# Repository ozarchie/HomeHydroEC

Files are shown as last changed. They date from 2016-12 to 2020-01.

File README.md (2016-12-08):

# HomeHydroEC
=============
An extension of Michael Ratcliffe's excellent EC project.   
<B>See the Project Wiki for a full description.  </B>  
https://github.com/ozarchie/HomeHydroEC/wiki  

## Extensions  
-------------
This project addresses the issue of polarization by implementing a square wave balanced resistor approach to measurement.  
An additional analog input channel is required.  
The 1k resistor is split in two as two 470R resistors and the probe inserted between the resistors.  
The voltage across the 470R sense resistor allows calculation of the sense current.  
The voltage across the prongs and the sense current allows determination of the electrical conductivity.  
An 18B20 sensor is connected to monitor the solution temperature.  

Schematic

Testing and documentation is underway. Documentation is included in the code.  

The Kcell of the probe is calculated using standard formula and measurements of the AC probe. 
EC Measurements agree well with Chinese TDC&EC meters.  
See the Project Wiki for a full description.  

## Original Work  

Original ideas and program published by -:  

www.MichaelRatcliffe.com/projects  
https://www.element14.com/community/community/design-challenges/vertical-farming/blog/2015/09/13/automated-green-house-blogs-main-page  
 
  28/8/2015  Michael Ratcliffe  Mike@MichaelRatcliffe.com

   This program is free software: you can redistribute it and/or modify
    it under the terms of the GNU General Public License as published by
    the Free Software Foundation, either version 3 of the License, or
    (at your option) any later version.

    This program is distributed in the hope that it will be useful,
    but WITHOUT ANY WARRANTY; without even the implied warranty of
    MERCHANTABILITY or FITNESS FOR A PARTICULAR PURPOSE.  See the
    GNU General Public License for more details.

    You should have received a copy of the GNU General Public License
    along with this program.  If not, see <http://www.gnu.org/licenses/>.

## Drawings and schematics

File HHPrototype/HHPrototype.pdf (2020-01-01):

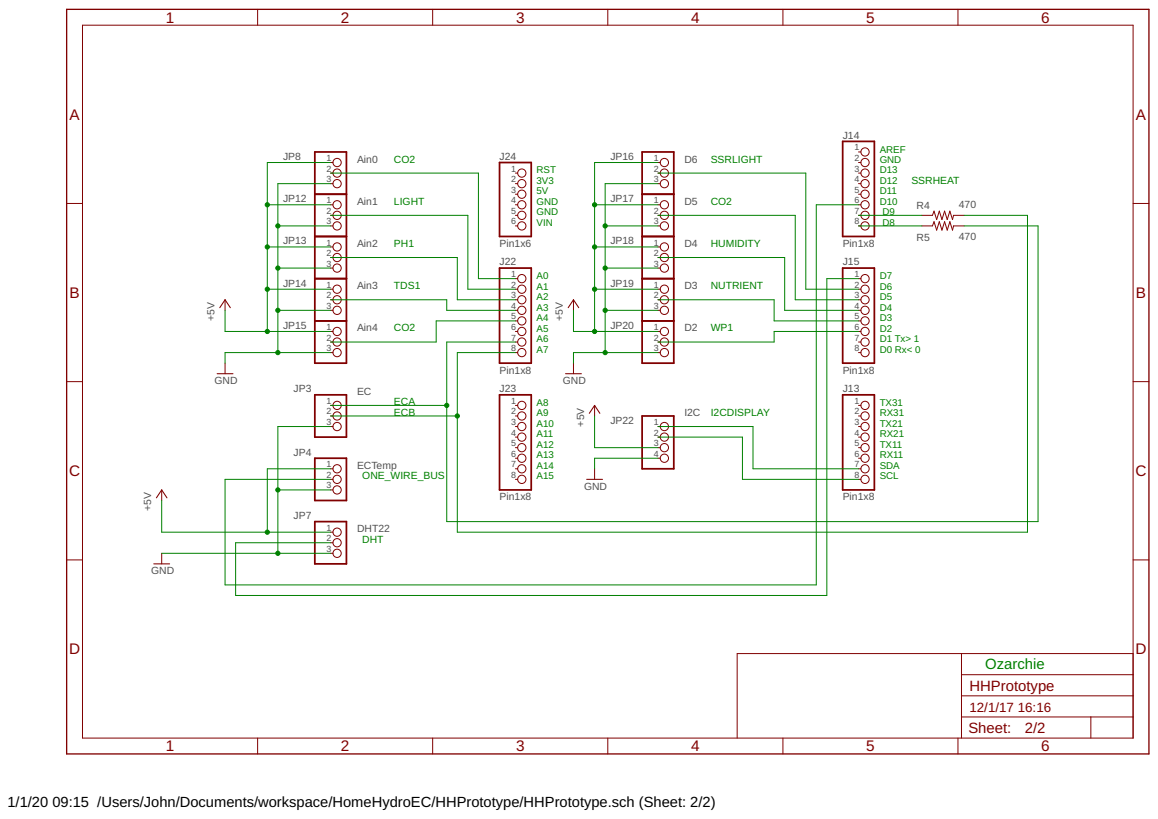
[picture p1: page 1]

1/1/20 09:15 /Users/John/Documents/workspace/HomeHydroEC/HHPrototype/HHPrototype.sch (Sheet: 2/2)

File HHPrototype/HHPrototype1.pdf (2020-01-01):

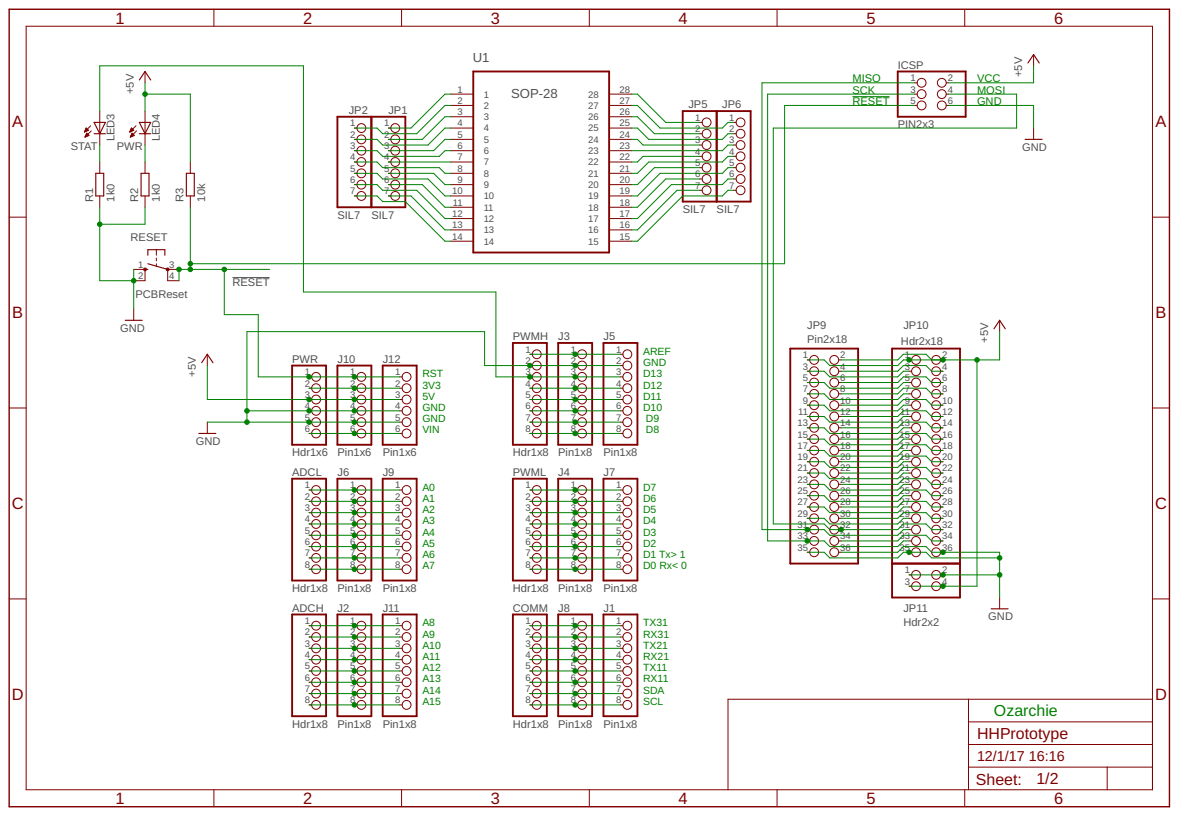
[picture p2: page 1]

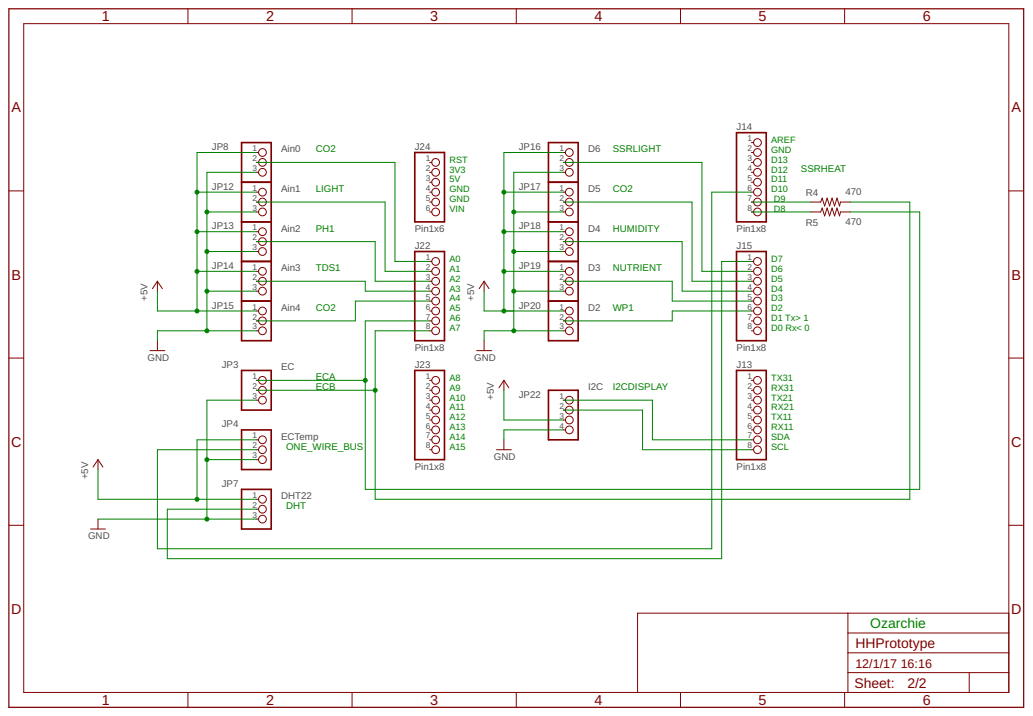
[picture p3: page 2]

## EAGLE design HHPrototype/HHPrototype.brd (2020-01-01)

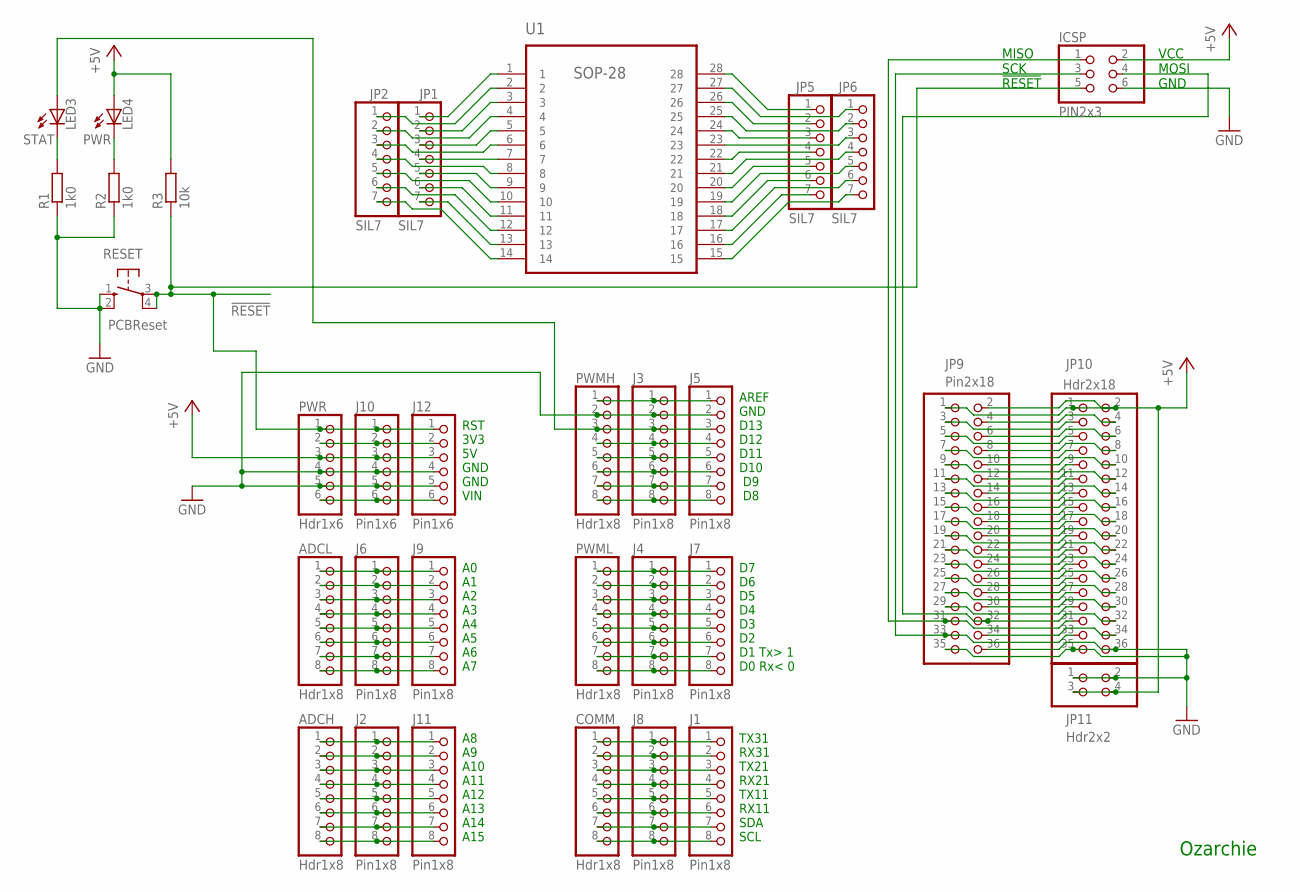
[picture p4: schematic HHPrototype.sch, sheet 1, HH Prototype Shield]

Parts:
ADCH: Hdr1x8; 1X08
ADCL: Hdr1x8; 1X08
COMM: Hdr1x8; 1X08
ICSP: PIN2x3; 2X03
J1, J2, J3, J4, J5, J6, J7, J8, J9, J11: Pin1x8; 1X08
J10, J12: Pin1x6; 1X06
JP1, JP2, JP5, JP6: SIL7; 1X07
JP9: Pin2x18; 2X18
JP10: Hdr2x18; 2X18
JP11: Hdr2x2; 2X02
LED3: STAT; CHIPLED_1206
LED4: PWR; CHIPLED_1206
PWMH: Hdr1x8; 1X08
PWML: Hdr1x8; 1X08
PWR: Hdr1x6; 1X06
R1, R2: 1k0; R0805
R3: 10k; R0805
RESET: PCBReset; B3F-10XX
U1: SOP-28; SOP50P1030X264-28N

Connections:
3V3: J10.2, J12.2, PWR.2
!RESET!: ICSP.5, J10.1, J12.1, PWR.1, R3.1, RESET.3, RESET.4 (P1)
+5V: ICSP.2, J10.3, J12.3, JP9.1, JP9.2, JP10.1, JP10.2, JP11.3, JP11.4, LED4.A, PWR.3, R3.2; also elsewhere on the board
A0: ADCL.1, J6.1, J9.1
A1: ADCL.2, J6.2, J9.2
A2: ADCL.3, J6.3, J9.3
A3: ADCL.4, J6.4, J9.4
A4: ADCL.5, J6.5, J9.5
A5: ADCL.6, J6.6, J9.6
A6: ADCL.7, J6.7, J9.7
A7: ADCL.8, J6.8, J9.8
A8: ADCH.1, J2.1, J11.1
A9: ADCH.2, J2.2, J11.2
A10: ADCH.3, J2.3, J11.3
A11: ADCH.4, J2.4, J11.4
A12: ADCH.5, J2.5, J11.5
A13: ADCH.6, J2.6, J11.6
A14: ADCH.7, J2.7, J11.7
A15: ADCH.8, J2.8, J11.8
AREF: J3.1, J5.1, PWMH.1
D0/RX0: J4.8, J7.8, PWML.8
D1/TX0: J4.7, J7.7, PWML.7
D2PWM: J4.6, J7.6, PWML.6
D3PWM: J4.5, J7.5, PWML.5
D4PWM: J4.4, J7.4, PWML.4
D5PWM: J4.3, J7.3, PWML.3
D6PWM: J4.2, J7.2, PWML.2
D7PWM: J4.1, J7.1, PWML.1
D8PWM: J3.8, J5.8, PWMH.8
D9PWM: J3.7, J5.7, PWMH.7
D10PWM: J3.6, J5.6, PWMH.6
D11PWM: J3.5, J5.5, PWMH.5
D12PWM: J3.4, J5.4, PWMH.4
D13PWM: J3.3, J5.3, LED3.A, PWMH.3
D14/TX3: COMM.1, J1.1, J8.1
D15/RX3: COMM.2, J1.2, J8.2
D16/TX2: COMM.3, J1.3, J8.3
D17/RX2: COMM.4, J1.4, J8.4
D18/TX1: COMM.5, J1.5, J8.5
D19/RX1: COMM.6, J1.6, J8.6
D20/SDA: COMM.7, J1.7, J8.7
D21/SCL: COMM.8, J1.8, J8.8
D22: JP9.3, JP10.3
D23: JP9.4, JP10.4
D24: JP9.5, JP10.5
D25: JP9.6, JP10.6
D26: JP9.7, JP10.7
D27: JP9.8, JP10.8
D28: JP9.9, JP10.9
D29: JP9.10, JP10.10
D30: JP9.11, JP10.11
D31: JP9.12, JP10.12
D32: JP9.13, JP10.13
D33: JP9.14, JP10.14
D34: JP9.15, JP10.15
D35: JP9.16, JP10.16
D36: JP9.17, JP10.17
D37: JP9.18, JP10.18
D38: JP9.19, JP10.19
D39: JP9.20, JP10.20
D40: JP9.21, JP10.21
D41: JP9.22, JP10.22
D42: JP9.23, JP10.23
D43: JP9.24, JP10.24
D44: JP9.25, JP10.25
D45: JP9.26, JP10.26
D46: JP9.27, JP10.27
D47: JP9.28, JP10.28
D48: JP9.29, JP10.29
D49: JP9.30, JP10.30
D53: JP9.34, JP10.34
GND: ICSP.6, J3.2, J5.2, J10.4, J10.5, J12.4, J12.5, JP9.35, JP9.36, JP10.35, JP10.36, JP11.1, JP11.2, PWMH.2, PWR.4, PWR.5, R1.1, R2.1, RESET.1 (S), RESET.2 (S1); also elsewhere on the board
MISO: ICSP.1, JP9.31, JP10.31
MOSI: ICSP.4, JP9.32, JP10.32
unnamed: LED3.C, R1.2
unnamed: LED4.C, R2.2
SCK: ICSP.3, JP9.33, JP10.33
SO1: JP1.1, U1.1
SO2: JP2.1, U1.2
SO3: JP1.2, U1.3
SO4: JP2.2, U1.4
SO5: JP1.3, U1.5
SO6: JP2.3, U1.6
SO7: JP1.4, U1.7
SO8: JP2.4, U1.8
SO9: JP1.5, U1.9
SO10: JP2.5, U1.10
SO11: JP1.6, U1.11
SO12: JP2.6, U1.12
SO13: JP1.7, U1.13
SO14: JP2.7, U1.14
SO15: JP6.7, U1.15
SO16: JP5.7, U1.16
SO17: JP6.6, U1.17
SO18: JP5.6, U1.18
SO19: JP6.5, U1.19
SO20: JP5.5, U1.20
SO21: JP6.4, U1.21
SO22: JP5.4, U1.22
SO23: JP6.3, U1.23
SO24: JP5.3, U1.24
SO25: JP6.2, U1.25
SO26: JP5.2, U1.26
SO27: JP6.1, U1.27
SO28: JP5.1, U1.28
VIN: J10.6, J12.6, PWR.6

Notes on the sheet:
RST 3V3 5V GND GND VIN
MISO SCK !RESET!
VCC MOSI GND
AREF GND D13 D12 D11 D10 D9 D8
D7 D6 D5 D4 D3 D2 D1 Tx> 1 D0 Rx< 0
A0 A1 A2 A3 A4 A5 A6 A7
A8 A9 A10 A11 A12 A13 A14 A15
TX31 RX31 TX21 RX21 TX11 RX11 SDA SCL
Ozarchie

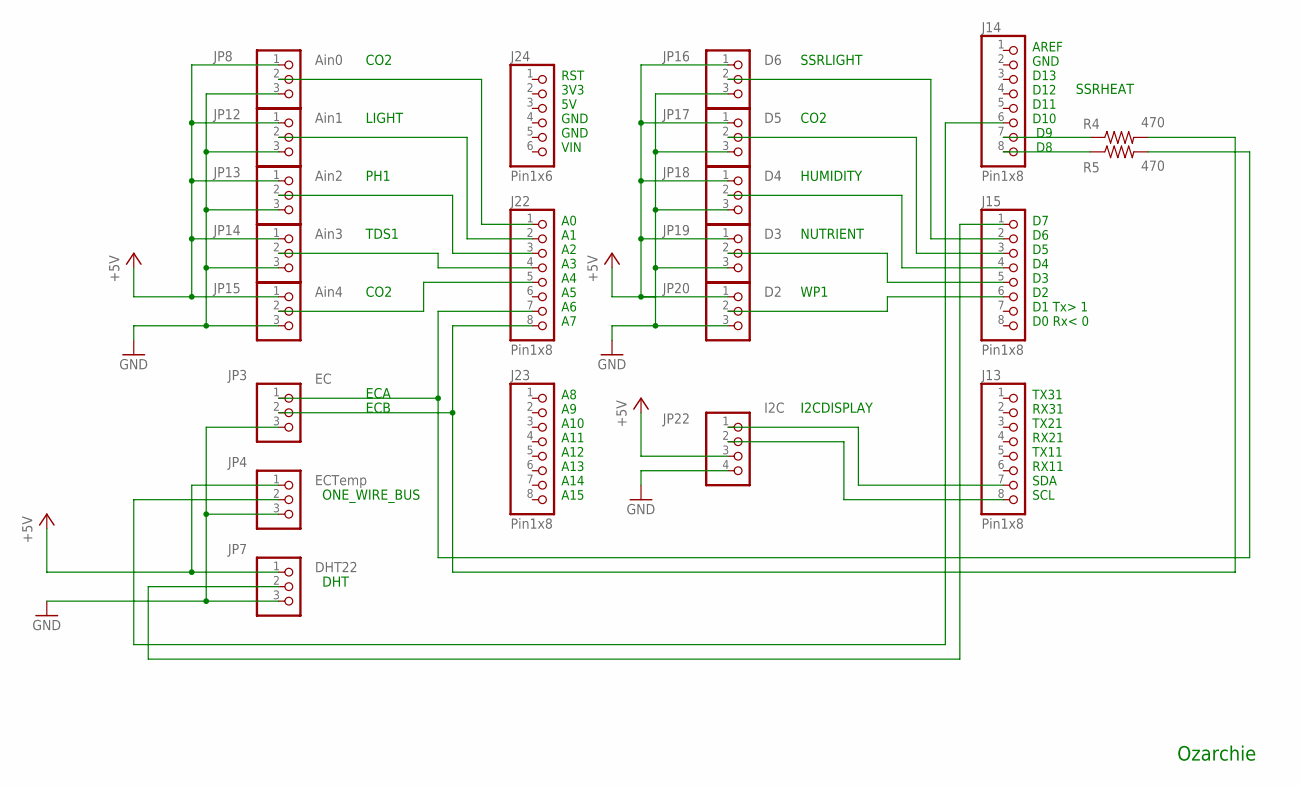
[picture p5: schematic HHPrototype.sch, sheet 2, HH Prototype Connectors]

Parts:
J13, J14, J15, J22, J23: Pin1x8; 1X08
J24: Pin1x6; 1X06
JP3: EC; 1X03
JP4: ECTemp; 1X03
JP7: DHT22; 1X03
JP8: Ain0; 1X03
JP12: Ain1; 1X03
JP13: Ain2; 1X03
JP14: Ain3; 1X03
JP15: Ain4; 1X03
JP16: D6; 1X03
JP17: D5; 1X03
JP18: D4; 1X03
JP19: D3; 1X03
JP20: D2; 1X03
JP22: I2C; 1X04
R4, R5: 470; 0207/2V

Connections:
+5V: JP4.1, JP7.1, JP8.1, JP12.1, JP13.1, JP14.1, JP15.1, JP16.1, JP17.1, JP18.1, JP19.1, JP20.1, JP22.3; also elsewhere on the board
GND: JP3.3, JP4.3, JP7.3, JP8.3, JP12.3, JP13.3, JP14.3, JP15.3, JP16.3, JP17.3, JP18.3, JP19.3, JP20.3, JP22.4; also elsewhere on the board
unnamed: J22.7, JP3.1, R5.2
unnamed: J15.6, JP20.2
unnamed: J15.5, JP19.2
unnamed: J15.4, JP18.2
unnamed: J15.3, JP17.2
unnamed: J15.2, JP16.2
unnamed: J22.1, JP8.2
unnamed: J22.2, JP12.2
unnamed: J22.3, JP13.2
unnamed: J22.4, JP14.2
unnamed: J22.5, JP15.2
unnamed: J13.7, JP22.1
unnamed: J13.8, JP22.2
unnamed: J15.1, JP7.2
unnamed: J22.8, JP3.2, R4.2
unnamed: J14.7, R4.1
unnamed: J14.6, JP4.2
unnamed: J14.8, R5.1

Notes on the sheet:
RST 3V3 5V GND GND VIN
A0 A1 A2 A3 A4 A5 A6 A7
A8 A9 A10 A11 A12 A13 A14 A15
Ozarchie
AREF GND D13 D12 D11 D10 D9 D8
D7 D6 D5 D4 D3 D2 D1 Tx> 1 D0 Rx< 0
TX31 RX31 TX21 RX21 TX11 RX11 SDA SCL
CO2
LIGHT
PH1
TDS1
ECA
ECB
SSRLIGHT
HUMIDITY
NUTRIENT
WP1
SSRHEAT
ONE_WIRE_BUS
DHT
I2CDISPLAY

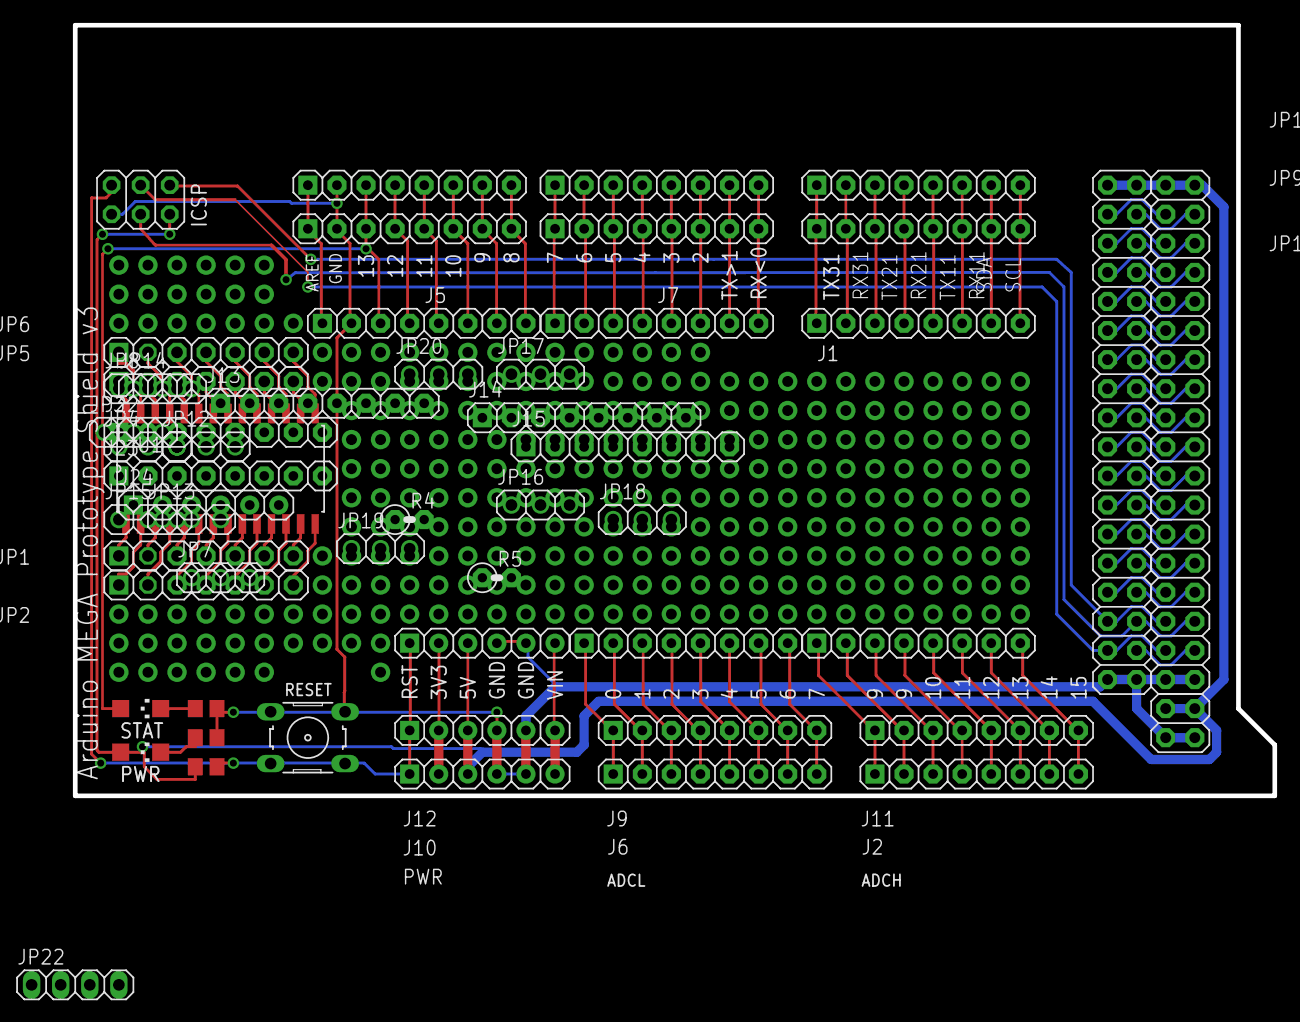
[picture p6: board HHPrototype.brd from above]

Board: 2 copper layers, 104.8 x 67.3 mm, 55 parts (0 on the bottom side), 124 nets.

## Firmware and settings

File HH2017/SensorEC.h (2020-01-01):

//*********** PPM Configuration Parameters ******************************//
// Hana      [USA]        PPMconversion:  0.5
// Eutech    [EU]         PPMconversion:  0.64
// Tranchen  [Australia]  PPMconversion:  0.7

#define PPMUS  0.5
#define PPMEU  0.64
#define PPMAu  0.7
#define PPM PPMAu               // <<<--- Change for your region

#define MAX_EC 10
#define MIN_EC 0
#define DEFAULT_EC 2

// Temperature defaults in centigrade
#define MAX_TEMP 60
#define MIN_TEMP -30
#define DEFAULT_TEMP 25

float PPMConst = PPM * 1000;    // Convert EC to ppm - Au

//************ EC Configuration Parameters *******************************//

float CalibrationKCl = 1.41;      // EC value of KCL Calibration solution (in mS/cm)
                                  // 0.01 D KCl solution @ 25°C
float CalibrationNaCl = 1014.9;   // EC value of NaCl Calibration solution (in uS/cm)
                                  // 0.05% NaCl solution @ 25°C
float TemperatureCoef = 0.019;    // Depends on chemical composition of solution
                                  // See below 0.019 = 1.9%/°C

float Rs = 470;                     // Current Sensing Resistor
float Ra = 25;                      // Estimated Source/Sink Resistance of powering Pins

float Vin = 5;                      // Power supply value

// Compensation for temperature
// ----------------------------
// conductivity = (Kcell / R) / (1 + (TemperatureCoef/100) * (T−25))


// Determination of the temperature coefficient (θ)
// ------------------------------------------------
//  By measuring the conductivity of a sample at temperature T1
//   close to Tref (25°C) and another temperature T2
//   coefficient by using the following equation:
//
//  θ = (κT2 - κT1) * 100 / (T2 - T1) * κT1
//   κT2 = Conductivity at T2
//   κT1 = Conductivity at T1
//  T2 should be approximately 10°C different from T1
//
// The temperature coefficients of the following electrolytes generally fall
// into the ranges shown below:
//  Acids: 1.0 - 1.6%/°C
//  Bases: 1.8 - 2.2%/°C
//  Salts: 2.2 - 3.0%/°C
//  Drinking water: 2.0%/°C
//  Ultrapure water: 5.2%/°C

//************ EC Probe Configuration Parameters **************************//

// Typical Conductivity values at 25°C
// -----------------------------------
//  Pure water            0.055 µS/cm
//  Deionised water       1 µS/cm
//  Rainwater             50 µS/cm
//  Drinking water        500 µS/cm
//  Industrial wastewater 5 mS/cm
//  Seawater              50 mS/cm
//  1 mol/l NaCl          85 mS/cm
//  1 mol/l HCl           332 mS/cm


// Calculate K from measurements of US style AC connector
// ------------------------------------------------------
// Area of prongs A = 2 * ((l * w) + (l * t)) // Side faces (two)
//                      + w * t               //  + End
//                      - 2 * (pi * r^2)      //  - Holes
//                      + (2 * pi * r) * t    //  + Internal annulus
//  where
//  l = length of prongs
//  w = width of prongs
//  t = thickness of prongs
//  r = radius of holes in prongs
//
// cell constant = Kcell = s/A
// ---------------------------
//  where
//  s = separation in cm between the electrodes (prongs)
//  A = area in cm2 of the electrodes (prongs)

// Input AC prong measurements in cm
// ---------------------------------
#define plength 1.7
#define pwidth 0.62
#define pthick 0.14
#define psepn 1.16
#define pradius 0.25
#define pi 3.17

// Calculated cell constant
// ------------------------
// One Prong Area = 2 * (Faces + sides) + end  - 2 * Circular hole + Internal annulus of hole
// float Ap = (2 * ((l * w) + (l * t))) + w * t - (2 * (pi * r * r)) + ((2 * pi * r) * t) ;
// float Kc = (s / (2 * Ap));          // Two prongs
// float K = Kc;                       // Calculated cell constant

// However, practice suggests that the other face and sides on each prong only contribute to 'fringe' effects.
// so ...
float  Ap = (plength * pwidth) + (plength * pthick) - pi * pradius * pradius;     // Surface area of one prong
float  Kc = (psepn / (2 * Ap));                                                   // Two prongs
float  K = Kc;

//************ EC Probe Related ******************************************//
int Polarity = 0;               // Polarity for this reading

float EC = 0;                     // EC - Temerature Compensated
float ECu = 0 ;                   // Uncompensated
int ppm = 0;                      // parts per million
char Units = 'm';                 // mS or uS

#define typeEC 0                // EC - Temerature Compensated
#define typeECu 1               // EC - UnCompensated
#define typePPM 2               // ppm - Temerature Compensated
#define typeRc 3                // Raw solution resistance - uncompensated

float ECVolts;                  // Sensing variables
float RsVolts;
float Vdrop = 0;
float Rc = 0;
float Ic = 0;

// The conductivity of a solution
// ------------------------------
// EC = K * G
// EC = K / R
// EC = conductivity (S/cm)
// G  = conductance (S), where G = 1/R
// K  = cell constant (cm-1)

// Frequency of measurements
// -------------------------
//  Measuring frequencies of a typical conductivity meter
//  94 Hz     in 4.000 µS and 40.00 µS ranges
//  46.9 Hz  in 400.0 mS and 2.000 S ranges
#define ECDelay 50              // 25 Hz

// Analog reference options
// ------------------------
// DEFAULT: the default analog reference of 5 volts (on 5V Arduino boards) or 3.3 volts (on 3.3V Arduino boards)
// INTERNAL: an built-in reference, equal to 1.1 volts on the ATmega168 or ATmega328 and 2.56 volts on the ATmega8 (not available on the Arduino Mega)
// INTERNAL1V1: a built-in 1.1V reference (Arduino Mega only)
// INTERNAL2V56: a built-in 2.56V reference (Arduino Mega only)
// EXTERNAL: the voltage applied to the AREF pin (0 to 5V only) is used as the reference.

#define AVolts Vin/1024           // = 5.00/1024

float ECTemperatureStart = 23.0;
float ECTemperatureFinish = 23.0;
 
float temp;

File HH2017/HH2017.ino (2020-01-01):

#include <avr/pgmspace.h>
#include "Arduino.h"

#include <Time.h>
#include <DS1307RTC.h>
#include <RTClib.h>

#include <Wire.h>
#include <LiquidCrystal_I2C.h>

#include <OneWire.h>
#include <DallasTemperature.h>

#include <DHT.h>   // Latest DHTnn library

#include "SensorEC.h"

#include <EEPROM.h>
#include "E2P_Map.h"

/*
//VARIABLES
*/
#define MSG_INTERVAL 10
#define LCD_INTERVAL 100

boolean stringComplete = false;
int serialcounter = 0;
int serialincounter = 0;

char SerialBuffer[80] = { 1,1,1,1,1,1,1,1,1,1,              // Testing, until the problem with PString() was found
                          2,2,2,2,2,2,2,2,2,2,
                          3,3,3,3,3,3,3,3,3,3,
                          4,4,4,4,4,4,4,4,4,4,
                          5,5,5,5,5,5,5,5,5,5,
                          6,6,6,6,6,6,6,6,6,6,
                          7,7,7,7,7,7,7,7,7,7,
                          8,8,8,8,8,8,8,8,8,8
                          };
int  pSerialBuffer = 0;
char* message[16] = {0,0,0,0,0,0,0,0,0,0,0,0,0,0,0,0};      // Maximum 16 elements in array

// RTC Interface
// -------------
tmElements_t tm;

char longdate[25] = "Jan  1, 2017 12:00:00 AM";
// char pH1_char[7] = "00.00";
// char pH2_char[7] = "00.00";
char Temp_char[8]= "";
char RH_char[7] = "00.00%";
char TDS1_char[11] = "0000.0ppm";
char TDS2_char[11] = "0000.0ppm";
char CO2_char[8] = "00.00%";
char Light_char[8] = "00.00%";

//Committed Light Settings
int Light_ON_hour = 18;
int Light_ON_min = 0;
int Light_OFF_hour = 6;
int Light_OFF_min = 0;

// Committed Pump Schedule Settings
// -------------------------------
int Pump_start_hour = 7;
int Pump_start_minute = 15;
int Pump_start_isAM = true;
int Pump_every_hours = 1;
int Pump_every_mins = 0;
int Pump_for = 15; //In Minutes
int Pump_repeat = 12; //Number of times per day

// Allow for pump schedules (Set in E2P_Map.h)
int Pump_hour_array[MAXREPEAT];
int Pump_minute_array[MAXREPEAT];
int Pump_isAM_array[MAXREPEAT];

/*
  SENSOR VARIABLES
 */
//Values the arduino sees
int pH1RawValue = 0;
int pH2RawValue = 0;
int TempRawValue = 0;
int RHRawValue = 0;
int TDS1RawValue = 0;
int TDS2RawValue = 0;
int CO2RawValue = 0;
int LightRawValue = 0;

//Values the humans see (after it has been calculated using raw values above ^^^ and their respected formulas)
float pH1Value = 0;
float pH2Value = 0;
float TempValue = 0;
float RHValue = 0;
float TDS1Value = 0;
float TDS2Value = 0;
float CO2Value = 0;
float LightValue = 0;

//PH
//Status Indicator Values
char  pH1_Status[4] = "OK";
float pH1Value_Low = 5.60;
float pH1Value_High = 6.10;
char  pH2_Status[4] = "OK";
float pH2Value_Low = 5.60;
float pH2Value_High = 6.10;

//Temp
char  Temp_Status[4] = "OK";
float TempValue_Low = 5.00;
float TempValue_High = 21.00;
//Accessory ON/OFF Values
float Heater_ON = 5.00;
float Heater_OFF = 21.00;
float AC_ON = 29.00;
float AC_OFF = 21.00;

//Humidty(RH)
char  RH_Status[4] = "OK";
float RHValue_Low = 30.00;
float RHValue_High = 80.00;
//Accessory ON/OFF Values
float Humidifier_ON = 40.00;
float Humidifier_OFF = 60.00;
float Dehumidifier_ON = 80.00;
float Dehumidifier_OFF = 60.00;

//TDS1
char  TDS1_Status[4] = "OK";
float TDS1Value_Low = 500.0;
float TDS1Value_High = 800.0;
//Accessory ON/OFF Values
float NutePump1_ON = 500.0;
float NutePump1_OFF = 800.0;
boolean MixPump1_Enabled = true;

//TDS2
char  TDS2_Status[4] = "OK";
float TDS2Value_Low = 500.0;
float TDS2Value_High = 800.0;
//Accessory ON/OFF Values
float NutePump2_ON = 500.0;
float NutePump2_OFF = 800.0;
boolean MixPump2_Enabled = true;

//CO2
char  CO2_Status[4] = "OK";
float CO2Value_Low = 60.00;
float CO2Value_High= 75.00;
//Accessory ON/OFF Values
float CO2_ON = 40.00;
float CO2_OFF = 60.00 ;
boolean CO2_Enabled = true;

//Light
char  Light_Status[4] = "OK";
float LightValue_Low = 20.00;
float LightValue_High = 95.00;


/*
 PIN DEFINITIONS
 */

 // Use analog reference
 
//float ArefValue = 5000.0 / 1024.0;   // Using default reference
float ArefValue = 2560.0 / 1024.0;   // Using 2V56 reference
//float ArefValue = 1100.0 / 1024.0;   // Using 1V1  reference

 // Analog pins
 // ===========
int CO2Pin = A0;
int LightPin = A1;
int pH1Pin = A2;
int pH2Pin = A2;
int TDS1Pin = A3;
int TDS2Pin = A3;
#define MAXINPUTS 8
int Input_Pin[MAXINPUTS] = { A0, A1, A2, A3, A4, A5, A6, A7 };

int pH1Ref = A5;        // Reference voltage from probe
int pH1Pwr = 12;        // Power for probe
#define NSAMPLES 10

// RH - DHT22 device for temperature and humidity
//#define DHTTYPE DHT11   // DHT 11
#define DHTTYPE DHT22   // DHT 22  (AM2302), AM2321
//#define DHTTYPE DHT21   // DHT 21 (AM2301)
#define DHTPIN 7                // DHT-22 on D7
DHT dht(DHTPIN, DHTTYPE);

// EC Probe Related
int ECAin=A6;                   // Probe A Sense Pin
int ECBin=A7;                   // Probe B Sense Pin 
int ECA=8;                      // Probe A Drive Pin
int ECB=9;                      // Probe B Drive Pin

// EC Temp Probe Related
#define EC_1WIRE 10             // Data wire For EC Temp Probe is plugged into pin D10 on the Arduino
OneWire ecWire(EC_1WIRE);      // Setup a oneWire instance to communicate with any OneWire devices
DallasTemperature ec_temp(&ecWire);  // Pass our oneWire reference to Dallas Temperature

// Water Temp Probe Related
#define WT_1WIRE 11         // Data wire For Water Temp Probes is plugged into pin D11 on the Arduino
OneWire wtWire(WT_1WIRE);  // Setup a oneWire instance to communicate with any OneWire devices
DallasTemperature wt_temp(&wtWire);// Pass our oneWire reference to Dallas Temperature

// Realtime Clock I2C - SDA/SCL
DS1307RTC rtc;

// LCD Display Related 
// Set the pins on the I2C chip used for LCD connections:
//                    addr, en,rw,rs,d4,d5,d6,d7,bl,blpol
LiquidCrystal_I2C lcd(0x27, 2, 1, 0, 4, 5, 6, 7, 3, POSITIVE);  // Set the LCD I2C address

// Digital pins
// ============
// Relays, SSR
// -----------
// Currently 6 relays
// MAXRELAYS set in E2P_Map.h
// Relays 5, 6 are SSR polarity

// Relay1_Pin = 2;  // Water Pump
// Relay2_Pin = 3;  // Nutrient
// Relay3_Pin = 4;  // Humidity
// Relay4_Pin = 5;  // CO2
// Relay5_Pin = 6;  //SSR (Light/Ballast)
// Relay6_Pin = 13; //SSR (Heater)

#define ON 1
#define OFF 0

#define WATERPUMP1 0
// #define WP2 1
#define NUTRIENT 1
#define HUMIDITY 2
#define pHADJUST 3
#define SSRLIGHT 4
#define SSRHEAT 5

int Relay_Pin[MAXRELAYS] = { 2, 3, 4, 5, 6, 13, 11, A15 };
uint8_t Relay_State[MAXRELAYS];
uint8_t Relay_isAuto[MAXRELAYS];

// Utility functions
// =================
boolean UIToStr(char *str, unsigned int val, uint8_t len, uint8_t dp)
{
  if (len > 5) return false;
  if (dp > len) return false;
  str += len;          // Point to end of string
  if (dp) str += 1;    //  add '.' if required
  *str = '\0';         // NULL terminate

  while (len--)
  {
    *--str = (val % 10) + '0';
    val /= 10;
    if ((--dp) == 0) *--str = '.'; 
  }
  return true;
}
boolean uint8ToStr(char *str, uint8_t val, uint8_t len, uint8_t dp)
{
  if (len > 3) return false;
  if (dp > len) return false;
  str += len;          // Point to end of string
  if (dp) str += 1;    //  add '.' if required
  *str = '\0';         // NULL terminate

  while (len--)
  {
    *--str = (val % 10) + '0';
    val /= 10;
    if ((--dp) == 0) *--str = '.'; 
  }
  return true;
}
/*
 SETUP
 */
void setup()
{
  int i;
  // Setup serial for boot reporting
  Serial.begin(9600);
  // SetuLCD for display
  //lcd.setBacklightPin ( BACKLIGHT_PIN, POSITIVE );
  //lcd.setBacklight ( HIGH );
  lcd.backlight();
  lcd.begin(20,4);               // initialize the lcd 
  lcd.home ();                   // go home
  
  lcd.setCursor ( 0, 2 );        // go to the third line
  lcd.print("HH Vers V17.0709"); 
  Serial.println("HH Vers V17.0709");
//  delay(50);    // Let user read, and wait for EEPROM  

  //Set Pin Modes for Inputs
  for (i = 0; i < MAXINPUTS; i++) {
    pinMode(Input_Pin[i], INPUT);
  }
  analogReference(INTERNAL2V56);

  // Setup EC Probe fir Input/Output
  EC_setup();
  
  //Set Pin Modes for Relays
  for (i = 0; i < MAXRELAYS; i++) {
    pinMode(Relay_Pin[i], OUTPUT);
  }
  pinMode(pH1Pwr, OUTPUT);
  
  // Read RTC
  // --------
  RestoreRTC();
  updatelongdate();
//  printtime();

//  Serial.println("Reading EEPROM into memory");
  // Load (and crc check) the E2P region values
  // If the region crc is wrong, load defaults

//  dumpcrc();
//  printE2PValues();
  lcd.setCursor ( 0, 3 );        // go to the bottom line  
  i = loadE2PValues();
  if (i != 0) {
    Serial.print("crc error count - ");
    Serial.println(i, DEC);
    lcd.print("EEPROM crc error");
    Serial.println(" Errors in EEPROM stored Values - enable print for details");
    dumpcrc();
    Serial.println("Defaults restored for values with errors");
    saveE2PValues();
    Serial.println("New values saved");
    dumpcrc();
    }
    else {
      lcd.print("EEPROM values loaded");
    }
    delay(1000);
}


/*
 LOOP
 */
 
void loop()
{
  char Month_array[12][4] = {"Jan","Feb","Mar","Apr","May","Jun","Jul","Aug","Sep","Oct","Nov","Dec"};
  int msgcount = 1;  // For sensor/relay messages
  int lcdcount = 1;  // For LCD Update
  
//  sendAllMessages();
  while (1) {
    if (msgcount > MSG_INTERVAL) {
//      updateSensorValues();
      sendserialmessages();
      CheckTimers();
      CheckSetPoints();
      msgcount = 0;
    }
    // Show on display
    if (lcdcount == 1) {
//      lcd.clear();
      lcd.setCursor ( 0, 0 );        // go to the top line
      if (hour() < 10) lcd.print(" ");
      lcd.print (hour());
      lcd.print(":");
      if (minute() < 10) lcd.print("0");
      lcd.print (minute());
      lcd.print(".");
      if (second() < 10) lcd.print("0");
      lcd.print (second());

//      lcd.setCursor ( 0, 1 );        // go to the bottom line
//      lcd.print("/");
//      lcd.print (year() % 2000);
//      if (month() < 10) lcd.print(" ");
      lcd.print("  ");
      lcd.print (Month_array[month()-1]);
      lcd.print(" ");
//      if (day() < 10) lcd.print(" ");
      lcd.print (day());
      
      lcd.setCursor ( 0, 1 );        // go to the bottom line
      lcd.print("pH ");
      lcd.print (pH1Value);
      lcd.setCursor ( 8, 1 );
      lcd.print("Lux ");
      lcd.print(LightValue);

    }
    if (lcdcount == LCD_INTERVAL) {
//      lcd.clear();
      lcd.setCursor ( 0, 0 );        // go to the top line
      lcd.print("RH ");
      lcd.print(RHValue);
      lcd.setCursor ( 8, 0 );
      lcd.print(" T ");
      lcd.print (TempValue);
      lcd.setCursor ( 0, 1 );        // go to the bottom line
      lcd.print("pp ");
      lcd.print (TDS1Value);
      lcd.setCursor ( 8, 1 );
      lcd.print(" T ");
      lcd.print(ECTemperatureFinish);
    }
    serialEvent();
    msgcount += 1;
    lcdcount += 1;
    if (lcdcount > LCD_INTERVAL*2) lcdcount = 0;
    delay(50);
  }
}

void printtime(void) {
  Serial.print(longdate);
  Serial.println();
}

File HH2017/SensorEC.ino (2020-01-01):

/*
  Electrical Conductivity Probes
  */


void EC_setup()
{

  pinMode(ECAin,INPUT);         // Always inputs
  pinMode(ECBin,INPUT);
}

/*
void EC_calibrate()
{
//  readTemp(0);                  // Read temperature
//  calibrateK();               // Calibrate K
  tod = now();
  EC=readECProbe(typeEC);

  if (EC < 1) {                 // Set display units
    EC *= 1000;
    ECu *= 1000;
    Units = 'u';
  }
  else if (EC < 1000) {
    EC *= 1000;
    ECu *= 1000;
    Units = 'm';    
  }
  else if (EC > 1000) {
    EC /= 1000;
    ECu /= 1000;
    Units = ' ';    
  }
  
  lcd.clear();
  lcd.setCursor ( 0, 0 );        // go to the top line
  lcd.print ("EC");
  lcd.setCursor ( 10, 0 );
  lcd.print(EC);
  lcd.print(Units);
  lcd.print("S");
  lcd.setCursor ( 0, 1 );        // go to the next line
  lcd.print ("EC (cal)");
  lcd.setCursor ( 10, 1 );
  lcd.print(CalibrationNaCl);
  lcd.print("uS");
  lcd.setCursor ( 0, 2 );        // go to the next line 
  lcd.print("Kcell");
  lcd.setCursor ( 10, 2 );
  lcd.print(K);
  lcd.setCursor ( 0, 3 );        // go to the next line    
  lcd.print("Ts ");
  lcd.print(TemperatureStart);
  lcd.setCursor ( 10, 3 ); 
  lcd.print("Tf ");
  lcd.print(TemperatureFinish);
    
  if ((TemperatureStart-TemperatureFinish) <= .2){
    Serial.print("Temperature stable to .2C - ");
    Serial.print("Ts ");
    Serial.print(j);
    Serial.print(", ");
    Serial.print(tod);
    Serial.print(", ");
    Serial.print(K);
    Serial.print(", ");
    Serial.print(TemperatureFinish);
    Serial.print(", ");
    Serial.print(ECu);
    Serial.print(", ");
    Serial.print(EC);
    Serial.print(", ");
    Serial.print(Rc);
    Serial.print(", ");             // Debug print
    Serial.println(Ic * 1000);

           
//    Serial.print("Calibration Solution EC: ");
//    Serial.print(CalibrationNaCl);
//    Serial.print("mS");

  }
  else{
    Serial.println("  Error - Wait For Temperature To settle");
    Serial.print("Ts ");
    Serial.print(TemperatureStart);
    Serial.print(", Tf ");
    Serial.print(TemperatureFinish);
  }
  delay(10000);
  j += 1;
}
*/

float readTemp(int tsensor) {
  float x;
  ec_temp.requestTemperatures(); // Send the command to get temperatures
  temp=ec_temp.getTempCByIndex(tsensor);
  if ((temp > MAX_TEMP) || (temp < MIN_TEMP)) temp = DEFAULT_TEMP;
  return(temp);
}


// Read data from EC probe
// -----------------------
// type typeEC  0   T Compensated Electrical conductivity
// type typeECu 1   Uncompensated Electrical conductivity
// type typePPM 2   T Compensated ppm
// type typeRc  3   Uncompensated Electrical Resistance

float EC_read(int type) {

  int i = 0;
  float x;
  ECVolts = 0;
  RsVolts = 0;
  Polarity = 0;
  
  ECTemperatureStart = readTemp(0);  // Read temperature   
  pinMode(ECA,OUTPUT);               // Set drive pins to outputs
  pinMode(ECB,OUTPUT);
  digitalWrite(ECA,LOW);            // Set PinA low
  digitalWrite(ECB,LOW);            // Set PinB low
  delay(ECDelay);                   // Wait til settled
  
// Measure voltages of probe - average 10 
  while(i < 10){    
// Alternately set polarity of sensing circuit to avoid polarizing the solution
//  and fouling the probe

    if (Polarity == 0) {
      digitalWrite(ECA,HIGH);   // Set PinA high
      digitalWrite(ECB,LOW);    // Set PinB low
    }
    else if (Polarity == 1) {
      digitalWrite(ECA,LOW);    // Set PinA low
      digitalWrite(ECB,HIGH);   // Set PinB high
    }
    delay(ECDelay);             // Wait for settling
    
    if (Polarity == 0) {               // Take alternate A->B, B->A readings
      x = analogRead(ECAin);
      ECVolts += analogRead(ECAin);    // This is not a mistake, First reading will be low
      x = analogRead(ECBin);
      RsVolts += analogRead(ECBin);      
      Polarity = 1;                     // Switch every measurement
    }
    else if (Polarity == 1) {
      x = analogRead(ECBin);
      ECVolts += analogRead(ECBin);    // This is not a mistake, First reading will be low
      x = analogRead(ECAin);
      RsVolts += analogRead(ECAin);
      Polarity = 0;                      // Switch every measurement 
    }
    i++;                            // Next measurement
    
//    Serial.print("ECVolts: ");      // Debug print
//    Serial.print((ECVolts/i)*AVolts);
//    Serial.print(", RsVolts: ");
//    Serial.print((RsVolts/i)*AVolts);
//    Serial.print(", Polarity: ");
//    Serial.println(Polarity);

  };

  digitalWrite(ECA,LOW);            // Set PinA low
  digitalWrite(ECB,LOW);            // Set PinB low
  delay(ECDelay);                   // Wait til settled
  pinMode(ECA,INPUT);               // Reset drive pins to inputs
  pinMode(ECB,INPUT);

  ECVolts *= (AVolts/10);           // Average of 10 measurements, convert to Volts
  RsVolts *= (AVolts/10);           // Average of 10 measurements, convert to Volts
  ECVolts -= RsVolts;               // Difference of volts across EC probe
  Ic = (RsVolts / (Rs + Ra));       // Calculate current through sense resistor
  Rc = ECVolts / Ic;                // Calculate EC Resistance from V=IR->R=V/I
  ECu = 1000 * (K / Rc);            // Calculate EC in mS
  ECTemperatureFinish = readTemp(0);  // Temperature Compensate the EC  
  EC = ECu / (1 + (TemperatureCoef * (ECTemperatureFinish - 25.0)));

//  if (Polarity == 0) Polarity = 1;  // Switch every new measurement set
//  else if (Polarity > 0) Polarity = 0;

  // Check for unreasonable values
  if ((EC > MAX_EC) || (EC < MIN_EC)) EC = DEFAULT_EC;    // Set a default for open connections

  if (type == typeEC) return(EC);             // Return EC
  if (type == typeECu) return(ECu);           // Return EC - uncompensated
  if (type == typePPM) return(EC * PPMConst); // Return ppm
  if (type == typeRc) return(Rc);             // Return Rc
  else return(DEFAULT_EC);
  
}

float EC_calibrateK(void) {  
  float Rec;                            // Place to store measured Rc
  Polarity = 0;                         // Reset probe polarity
  ECTemperatureStart = readTemp(0);       // Read temperature 
  Rec  = EC_read(typeRc);           // Read Rc A->B
  Rec += EC_read(typeRc);           // Read Rc B->A
  Rec /= 2;                             // Average two readings
  
// Temperature Compensate the EC of solution
  ECTemperatureFinish = readTemp(0);     
  EC=CalibrationNaCl*(1+(TemperatureCoef*(ECTemperatureFinish-25.0)));
// EC = K/R
// K = EC/R

  K = 1000*( EC / Rec) ;                // Calculate K
  return(K);
}

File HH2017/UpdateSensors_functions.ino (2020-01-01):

/*
// UPDATE SENSOR VALUES
*/

//READ ALL SENSOR VALUES AND CONVERT FOR LCD DISPLAY
void updateSensorValues() {
//  Serial.println("Updating sensor data ... "); 
//  analogReference(DEFAULT);  //Seems more accurate.
// pH SENSORS
  // pH1
  int pH1Sum;    // pH averaging
  int j;

  digitalWrite(pH1Pwr, HIGH);          // Turn the power On
  delay(2000);          // Wait for startup
  
  analogRead(pH1Pin);  //Get ADC to switch to correct pin
  delay(50); //Wait for Pin to Change

  pH1Sum = 0;
  j = 0;
  while(j < NSAMPLES) {
    pH1Sum = pH1Sum + analogRead(pH1Pin);
    delay(10);        // Short delay
    j++;
  }

//  Serial.print("Digital reading   - ");
//  Serial.print(pH1Sum);
//  Serial.print(", ");
  pH1RawValue = pH1Sum;
//  Serial.print(pH1RawValue);
//  Serial.print(": phRef - ");
  
  analogRead(pH1Ref); //Get ADC to switch to correct pin
  delay(50); //Wait for Pin to Change

  pH1Sum = 0;
  j = 0;
  while(j < NSAMPLES) {
    pH1Sum = pH1Sum + analogRead(pH1Ref);
    delay(10);        // Short delay
    j++;
  }

//  Serial.print(pH1Sum);
//  Serial.print(", ");
//  Serial.print(pH1Sum);
//  Serial.println("");
  
//  Serial.print("Analog conversion - ");
  pH1RawValue = pH1RawValue - pH1Sum;         // Subtract reference
  pH1Value = pH1RawValue;                     // Convert to float
//  Serial.print(pH1Value, 2);
//  Serial.print(", ");
  pH1Value = (pH1Value / NSAMPLES) * ArefValue;            // Convert to mV
//  Serial.print(pH1Value, 2);
//  Serial.print(", ");  
  pH1Value = (7.00 - (pH1Value / 89.0));     //  Convert to pH (89mV/1pH)
//  Serial.println(pH1Value);
//  Serial.print("");

  if(isnan(pH1Value)){
    pH1Value = 0;        
  }
  if (pH1Value < 0) pH1Value = 0;
  if (pH1Value > 14) pH1Value = 14;
//  UIToStr(pH1_char, pH1Value, 5, 1);
//  strcat(pH1_char,"pH");
//  Serial.println(pH1_char);

  digitalWrite(pH1Pwr, LOW);          // Turn the power Off

  // pH2
/*
  float pH2Sum = 0;
  j = 0;
  analogRead(pH2Pin);  //Get ADC to switch to correct pin
  delay(15); //Wait for Pin to Change

  while(j<30) {
    pH2Sum = pH2Sum + analogRead(pH2Pin);
    j++;
  }
  pH2RawValue = pH2Sum/30;

  pH2Value = (0.0178 * pH2RawValue - 1.889);
  if(isnan(pH2Value)){
    pH2Value = 0;        
  }

  UIToStr(pH2_char, pH2Value, 5, 1); 
  strcat(pH1_char,"pH");

// Temperature and Humidity

  dht.read22(DHTPIN);  //Use updated DHT library for hum, temp

  // DHT22 Temperature
  TempValue=dht.temperature;
  if(isnan(TempValue)){
    TempValue = 0;        
  }
  UIToStr(Temp_char, TempValue, 5, 2);
  strcat(Temp_char," C"); 
  
  // DHT22 Humidity
  RHValue = dht.humidity;
  if (isnan(RHValue)) {
    RHValue = 0;
  } 
  UIToStr(RH_char, RHValue, 5, 2);
  if (RHValue < 10){
    strcat(RH_char,"% ");
  } 
  else {
    strcat(RH_char,"%");
  }
*/
  
// TDS/EC

  EC = EC_read(2);
/*  
  float TDS1Sum = 0;
  j = 0;
  analogRead(TDS1Pin);  //Get ADC to switch to correct pin
  delay(15); //Wait for Pin to Change

  while(j<10) {
    TDS1Sum = TDS1Sum + analogRead(TDS1Pin);
    j++;
  }
  TDS1RawValue = TDS1Sum/((j-1) * 2);
  TDS1Value = ((TDS1RawValue * 1000.0)/1024.0);
  if(isnan(TDS1Value)){
    TDS1Value = 0;        
  }
  */
  TDS1Value = EC;
  UIToStr(TDS1_char, TDS1Value, 5, 2);
  strcat(TDS1_char," ppm");    
  
  float TDS2Sum = 0;
  j = 0;
  analogRead(TDS2Pin);  //Get ADC to switch to correct pin
  delay(15); //Wait for Pin to Change

  while(j<10) {
    TDS2Sum = TDS2Sum + analogRead(TDS2Pin);
    j++;
  }
  TDS2RawValue = TDS2Sum/((j-1) * 2);
  TDS2Value = ((TDS2RawValue * 1000.0)/1024.0);
  if(isnan(TDS2Value)){
    TDS2Value = 0;        
  }
  UIToStr(TDS2_char, TDS2Value, 5, 2);
  strcat(TDS2_char," ppm");   
  
    
// CO2

  float CO2Sum = 0;
  j = 0;
  analogRead(CO2Pin);  //Get ADC to switch to correct pin
  delay(15); //Wait for Pin to Change

  while(j<10) {
    CO2Sum = CO2Sum + analogRead(CO2Pin);
    j++;
  }
  CO2RawValue = CO2Sum/((j-1) * 2);
  CO2Value = ((CO2RawValue * 100.0)/1024.0);
  if(isnan(CO2Value)){
    CO2Value = 0;        
  }
  UIToStr(CO2_char, CO2Value, 5, 2);
  strcat(CO2_char," ppm");   
 
  
// LIGHT

  float LightSum = 0;
  j = 0;
  analogRead(LightPin);  //Get ADC to switch to correct pin
  delay(10); //Wait for Pin to Change
  
  while(j<10) {
    LightSum = LightSum + analogRead(LightPin);
    j++;
  }
  LightRawValue = LightSum/10;
  LightValue = ((LightRawValue * 100.0) / 1024.0);
  if (isnan(LightValue)) {
    LightValue = 0;
  } 
  UIToStr(Light_char, LightValue, 5, 2);
  if (LightValue < 10){
    strcat(Light_char,"% ");
  } 
  else {
    strcat(Light_char,"%");
  }

// CHECK LIMITS  
  //pH
  if (pH1Value < pH1Value_Low) {
    strcpy(pH1_Status,"LOW");
  } 
  else if (pH1Value > pH1Value_Low && pH1Value < pH1Value_High) {
    strcpy(pH1_Status,"OK");
  } 
  else if (pH1Value > pH1Value_High) {
    strcpy(pH1_Status,"HIGH");
  }
  if (pH2Value < pH2Value_Low) {
    strcpy(pH2_Status,"LOW");
  } 
  else if (pH2Value > pH2Value_Low && pH2Value < pH2Value_High) {
    strcpy(pH2_Status,"OK");
  } 
  else if (pH2Value > pH2Value_High) {
    strcpy(pH2_Status,"HIGH");
  }
  //Temperature
  if (TempValue < TempValue_Low) {
    strcpy(Temp_Status,"LOW");
  } 
  else if (TempValue > TempValue_Low && TempValue < TempValue_High) {
    strcpy(Temp_Status,"OK");
  } 
  else if (TempValue > TempValue_High) {
    strcpy(Temp_Status,"HIGH");
  }
  //RH
  if (RHValue < RHValue_Low) {
    strcpy(RH_Status,"LOW");
  } 
  else if (RHValue > RHValue_Low && RHValue < RHValue_High) {
    strcpy(RH_Status,"OK");
  }
  else if (RHValue < RHValue_High) {
    strcpy(RH_Status,"HIGH");
  }
  //TDS1
  if (TDS1Value < TDS1Value_Low) {
    strcpy(TDS1_Status,"LOW");
  } 
  else if (TDS1Value > TDS1Value_Low && TDS1Value < TDS1Value_High) {
    strcpy(TDS1_Status,"OK");
  } 
  else if (TDS1Value < TDS1Value_High) {
    strcpy(TDS1_Status,"HIGH");
  }
  //TDS2
  if (TDS2Value < TDS2Value_Low) {
    strcpy(TDS2_Status,"LOW");
  } 
  else if (TDS2Value > TDS2Value_Low && TDS2Value < TDS2Value_High) {
    strcpy(TDS2_Status,"OK");
  } 
  else if (TDS2Value < TDS2Value_High) {
    strcpy(TDS2_Status,"HIGH");
  }
  //CO2
  if (CO2Value < CO2Value_Low) {
    strcpy(CO2_Status,"LOW");
  } 
  else if (CO2Value > CO2Value_Low && CO2Value < CO2Value_High) {
    strcpy(CO2_Status,"OK");
  } 
  else if (CO2Value > CO2Value_High){
    strcpy(CO2_Status,"HIGH");
  }
  //Light
  if (LightValue < LightValue_Low) {
    strcpy(Light_Status,"LOW");
  } 
  else if (LightValue > LightValue_Low && LightValue < LightValue_High) {
    strcpy(Light_Status,"OK");
  } 
  else if (LightValue < LightValue_High) {
    strcpy(Light_Status,"HIGH");
  }
}

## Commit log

2016-12-07 Initial rework of Michael Ratcliffe's code
    Rework to change mode of operation to ‘AC”.
    This required some changes to the hardware - documentation is under way.
    The code now has polarity, so that measurements do not polarise the
    solution.
    Testing is user way, with initial results comparing well with Chinese
    handheld devices.
    [SensorEC.ino]
2016-12-08 Update for Wiki
    Wiki and start of schematics
    [Arduino_MEGA2560_ref.brd, Arduino_MEGA2560_ref.sch]
2016-12-08 Schematic for EC Sensor
    [Arduino_MEGA2560_ref.brd, Arduino_MEGA2560_ref.sch, Sh2560.sch]
2016-12-08 Add pdf
    [Sh2560.sch]
2020-01-01 Update for Home Hydro Project
    Uses the EC Sensor in a complete Home Hydro project
    [HHModules.sch, HHPrototype.brd, HHPrototype.fzz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]

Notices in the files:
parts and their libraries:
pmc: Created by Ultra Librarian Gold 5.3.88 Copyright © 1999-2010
